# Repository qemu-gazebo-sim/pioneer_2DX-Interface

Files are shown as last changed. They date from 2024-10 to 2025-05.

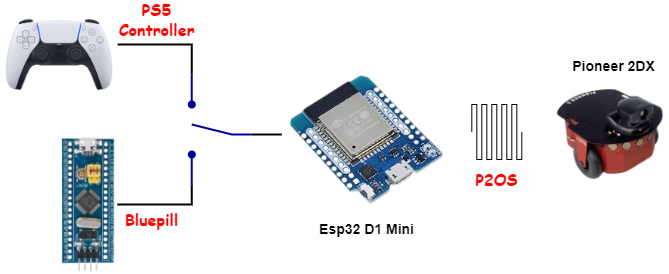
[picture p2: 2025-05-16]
docs/diagramas-test_setup-pioneer_2dx_interface.drawio.png

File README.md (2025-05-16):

<h1 align="center">🤝 Pioneer 2 - Interface | Electronic MVP</h1>
<p align="center"> Electronic Module for the connection between pioneer 2 and Esp32</p>

boards

## 🌎 Real board in the robot

real_robot_with_the_board

## 🧠 Overall board functionality

board_idea

The Pioneer 2DX Interface has the mission to perform the computational logic behind the communication with the Pioneer 2DX and enable for an outside electronic device to send and receive data from the robot. Being more specific for this project, the Pioneer 2DX interface firmware has three main tasks:

- Connect the ESP32 D1 Mini with the bluepill
- Connect the ESP32 D1 Mini with a PS5 controller
- Connect the ESP32 D1 Mini with the pioneer 2DX

The Pioneer 2DX interface allows either a PS5 controller or the Bluepill device to send data to the ESP32, but never simultaneously, as shown in Figure 21. The complete code developed for this interface is available in the GitHub repository of our organization.

The PS5 Controller was added to the project to make it easier to validate the robot’s mechanical and electrical flow without needing to use the autonomous code. This approach allows for identifying issues without suspecting the bluepill code.

algorithm logic

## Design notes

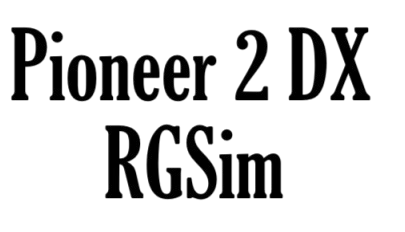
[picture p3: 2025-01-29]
docs/Title.png

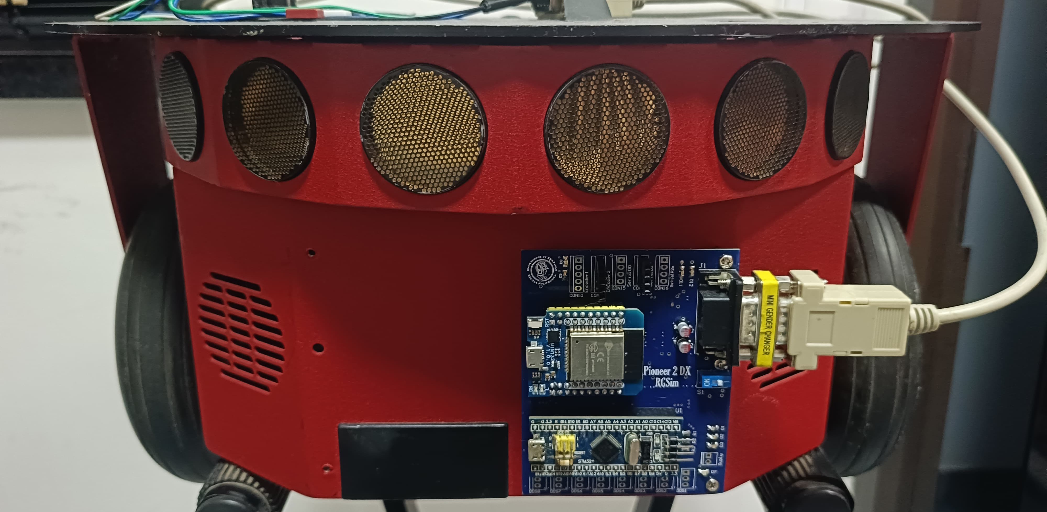
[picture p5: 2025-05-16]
docs/real_robot.jpeg

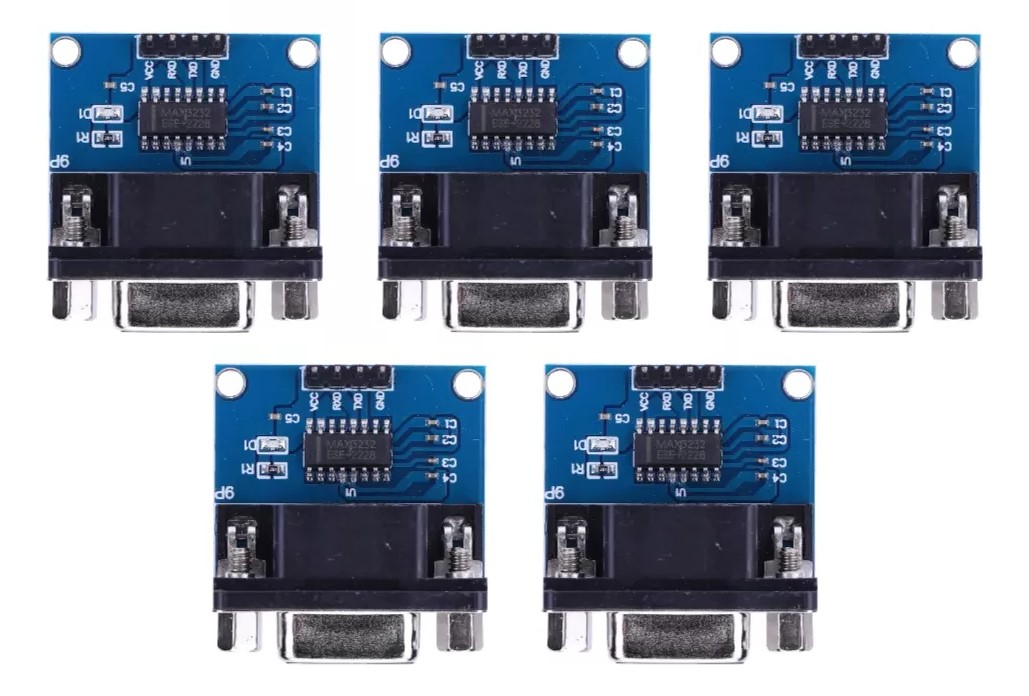
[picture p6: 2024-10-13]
docs/D_NQ_NP_2X_858012-MLB78559910960_082024-F.jpg

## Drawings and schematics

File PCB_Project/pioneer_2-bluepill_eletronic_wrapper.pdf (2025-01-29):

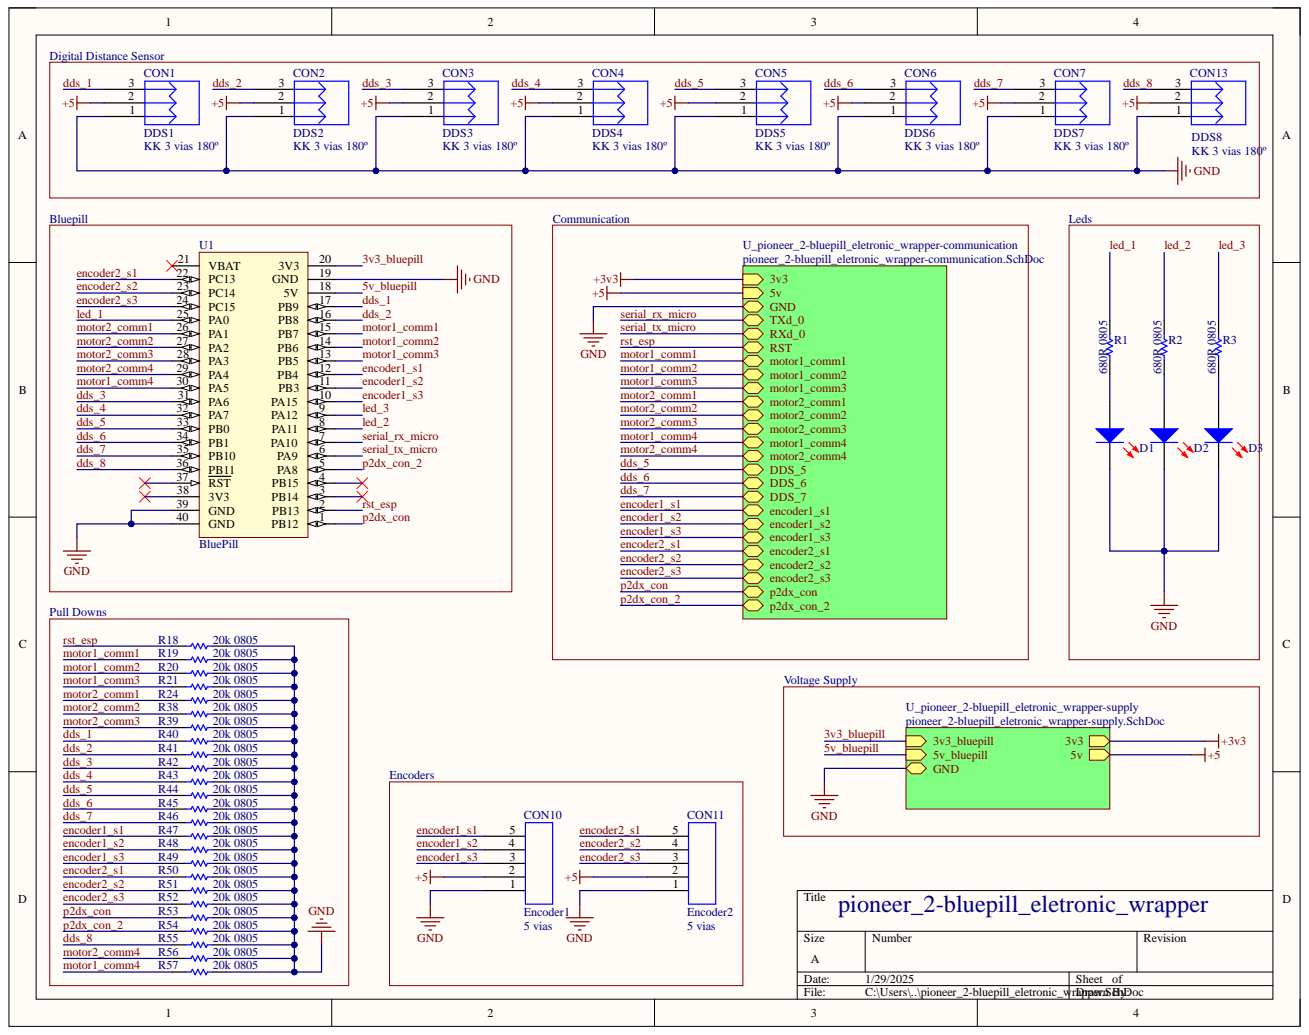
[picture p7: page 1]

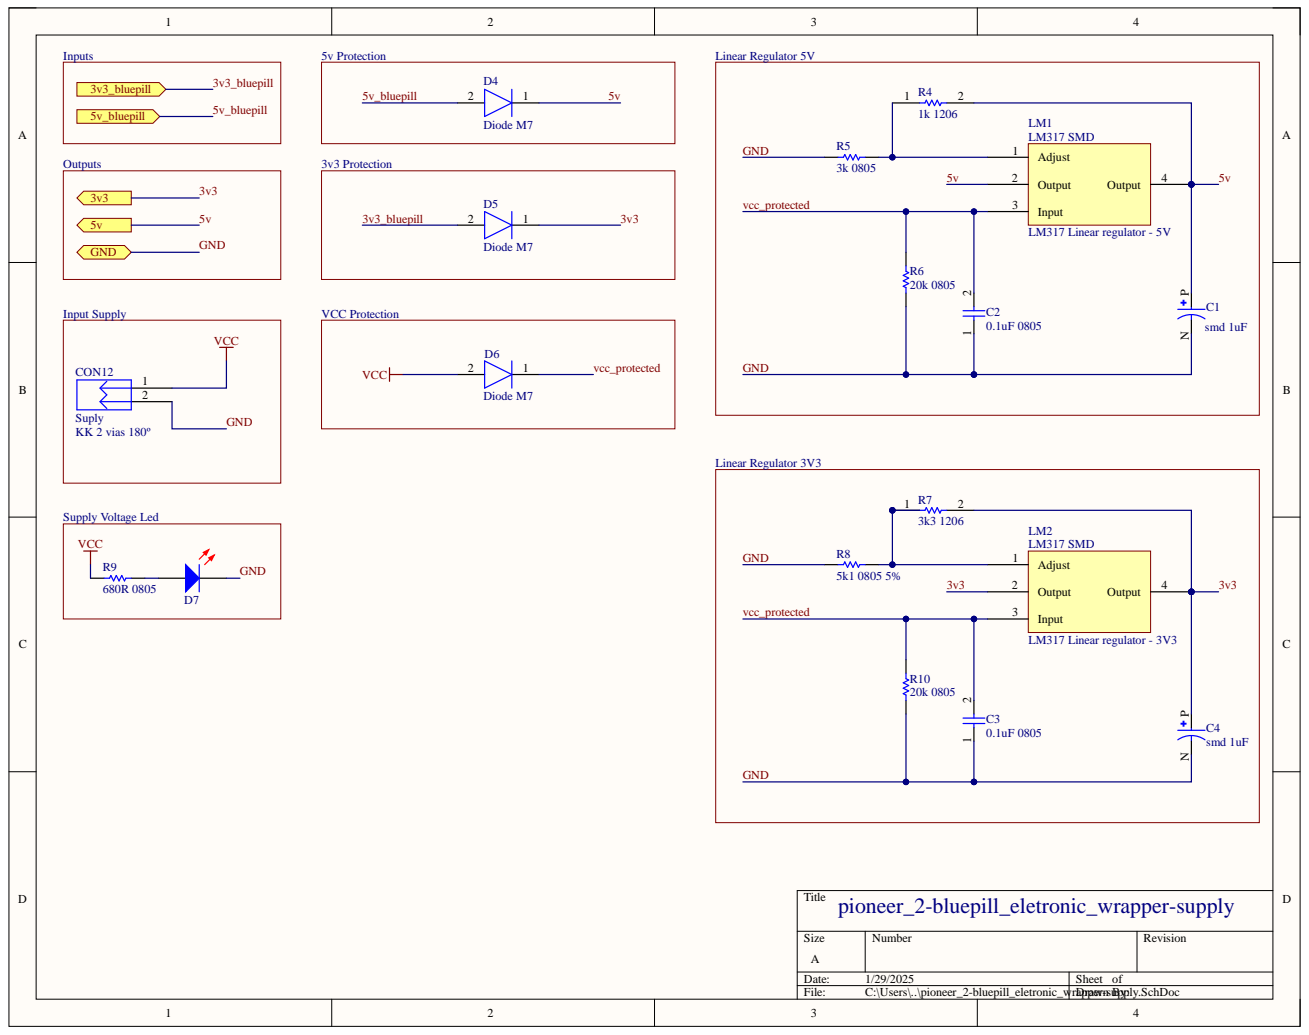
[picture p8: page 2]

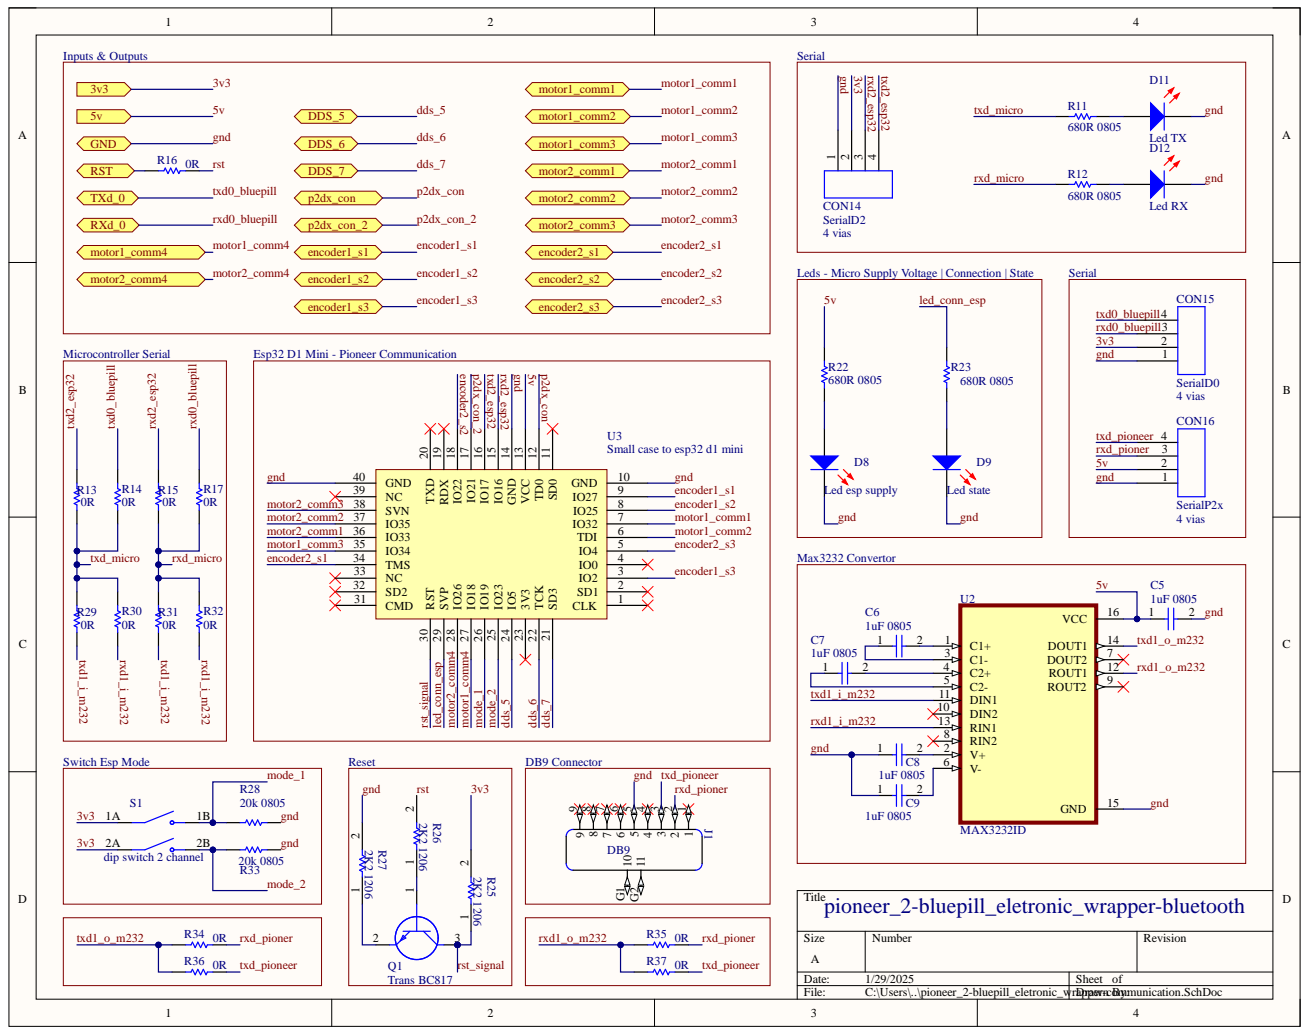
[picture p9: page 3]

Leds - Micro Supply Voltage | Connection | State

Small case to esp32 d1 mini

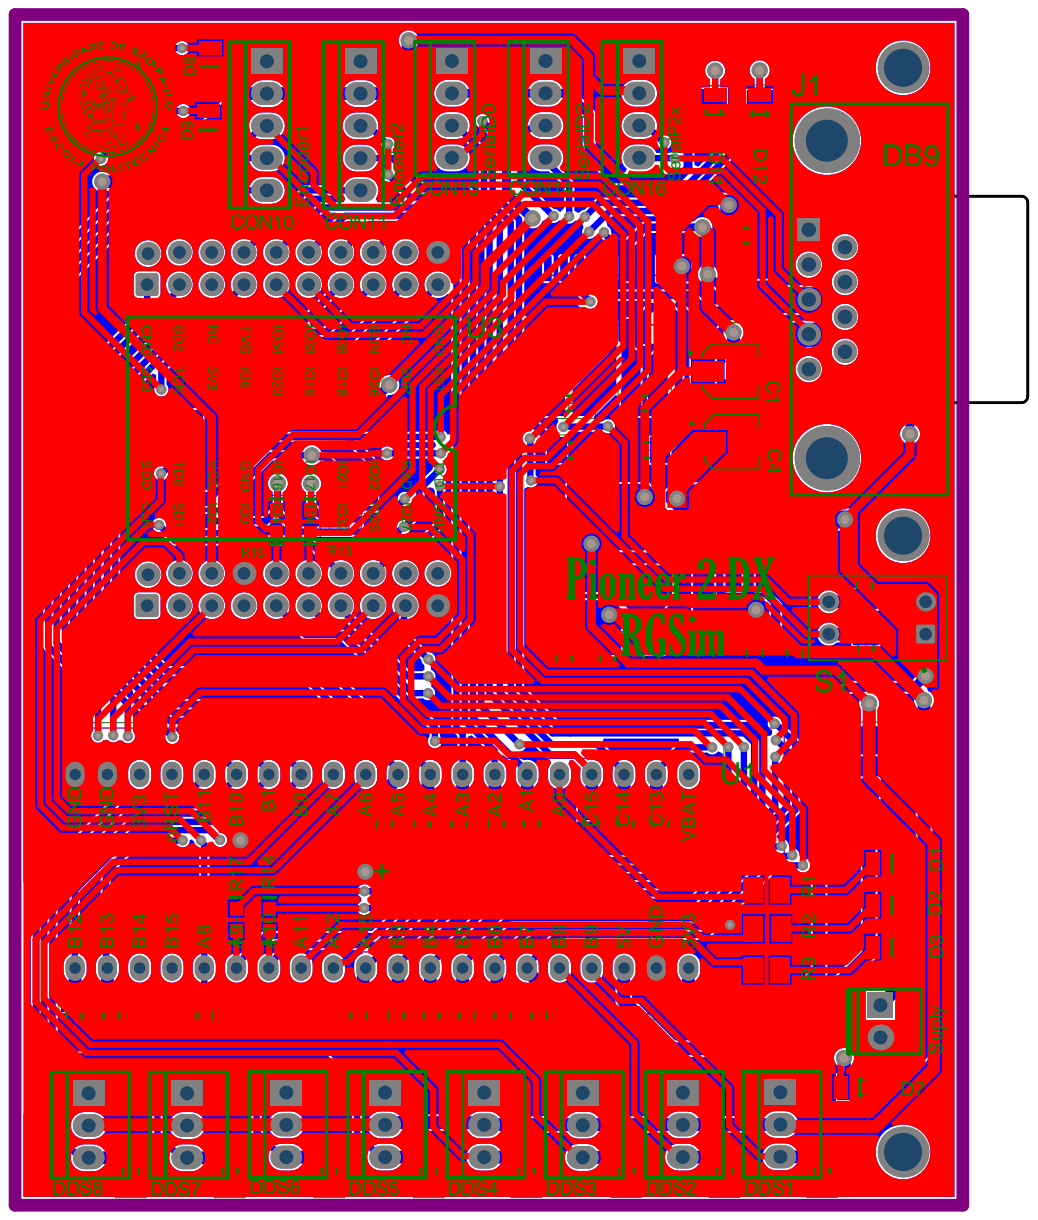
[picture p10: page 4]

Comment | Description | Designator | Footprint | LibRef | Quantity
smd 1uF | Aluminum Organic Polymer Capacitors smd 50volts 1uF | C1, C4 | CAP_EEE1HA2R2SR | Cap. Elet. smd 1uF 50V | 2
0.1uF 0805 | capacitor 0805 | C2, C3 | CAPACITOR 0805 | CAP 0805 | 2
1uF 0805 | capacitor 0805 | C5, C6, C7, C8, C9 | CAPACITOR 0805 | CAP 0805 | 5
DDS1 | Conector KK 2.54mm 3 vias | CON1 | KK_3vias_180º | KK_2.54_3vias | 1
DDS2 | Conector KK 2.54mm 3 vias | CON2 | KK_3vias_180º | KK_2.54_3vias | 1
DDS3 | Conector KK 2.54mm 3 vias | CON3 | KK_3vias_180º | KK_2.54_3vias | 1
DDS4 | Conector KK 2.54mm 3 vias | CON4 | KK_3vias_180º | KK_2.54_3vias | 1
DDS5 | Conector KK 2.54mm 3 vias | CON5 | KK_3vias_180º | KK_2.54_3vias | 1
DDS6 | Conector KK 2.54mm 3 vias | CON6 | KK_3vias_180º | KK_2.54_3vias | 1
DDS7 | Conector KK 2.54mm 3 vias | CON7 | KK_3vias_180º | KK_2.54_3vias | 1
Encoder1 | holes 2.54mm 5 vias | CON10 | 5vias | 2.54_5vias | 1
Encoder2 | holes 2.54mm 5 vias | CON11 | 5vias | 2.54_5vias | 1
Suply | Conector KK 2.54mm 2 vias | CON12 | KK_2VIAS_180º | KK_2.54_2vias | 1
DDS8 | Conector KK 2.54mm 3 vias | CON13 | KK_3vias_180º | KK_2.54_3vias | 1
SerialD2 | holes 2.54mm 4 vias | CON14 | 4vias | 2.54_4vias | 1
SerialD0 | holes 2.54mm 4 vias | CON15 | 4vias | 2.54_4vias | 1
SerialP2x | holes 2.54mm 4 vias | CON16 | 4vias | 2.54_4vias | 1
LED 3MM RED | LED 3MM RED | D1, D2, D3, D7 | LED RED | LED 3MM RED | 4
Diode M7 | Diode, SMA, 1000V, 1A, 150°C | D4, D5, D6 | DIOM505270X240 | Diode M7 | 3
Led esp supply | LED 3MM RED | D8 | LED RED | LED 3MM RED | 1
Led state | LED 3MM RED | D9 | LED RED | LED 3MM RED | 1
Led TX | LED 3MM RED | D11 | LED RED | LED 3MM RED | 1
Led RX | LED 3MM RED | D12 | LED RED | LED 3MM RED | 1
DB9 | Cable Grip 0.38 ~ 0.50 (9.5mm ~ 12.7mm) Aluminum - Silver | J1 | *DB9_DB9(Primary) | DB9 | 1
LM317 Linear regulator - 5V | SOT223 | LM1 | SOT-223-2 | lm317 smd | 1
LM317 Linear regulator - 3V3 | SOT223 | LM2 | SOT-223-2 | lm317 smd | 1
Trans BC817 | Transistor BJT NPN BC817-25-7-F | Q1 | SOT96P240X110-3N | Trans BC817 | 1
680R 0805 | 0805 | R1, R2, R3, R9, R11, R12, R22, R23 | RESISTOR 0805 | RES 0805 5% | 8
1k 1206 | RES 1206 5% | R4 | RESC3216X60N | RES 1206 | 1
3k 0805 | 0805 | R5 | RESISTOR 0805 | RES 0805 5% | 1
20k 0805 | 0805 | R6, R10, R18, R19, R20, R21, R24, R28, R33, R38, R39, R40, R41, R42, R43, R44, R45, R46, R47, R48, R49, R50, R51, R52, R53, R54, R55, R56, R57 | RESISTOR 0805 | RES 0805 5% | 29
3k3 1206 | RES 1206 5% | R7 | RESC3216X60N | RES 1206 | 1
5k1 0805 5% | 0805 | R8 | RESISTOR 0805 | RES 0805 5% | 1
0R | 0603 | R13, R14, R15, R16, R17, R29, R30, R31, R32, R34, R35, R36, R37 | RESISTOR 0603 | RES 0603 5% | 13
2K2 1206 | RES 1206 5% | R25, R26, R27 | RESC3216X60N | RES 1206 | 3
dip switch 2 channel | DS02-254-2L-02BE | S1 | SW_DS02-254-2L-02BE | dip switch 2 channel | 1
BluePill | BluePill - STMDuino (STM32F103) | U1 | BluePill | CMP-010-000000-1 | 1
MAX3232ID | 3-V to 5.5-V multichannel RS-232 line driver & receiver 16-SOIC -40 to 85 | U2 | SOIC127P600X175-16N | MAX3232ID | 1
Small case to esp32 d1 mini | ESP32 D1 Mini | U3 | ESP32 D1 MINI | ESP32 D1 Mini | 1

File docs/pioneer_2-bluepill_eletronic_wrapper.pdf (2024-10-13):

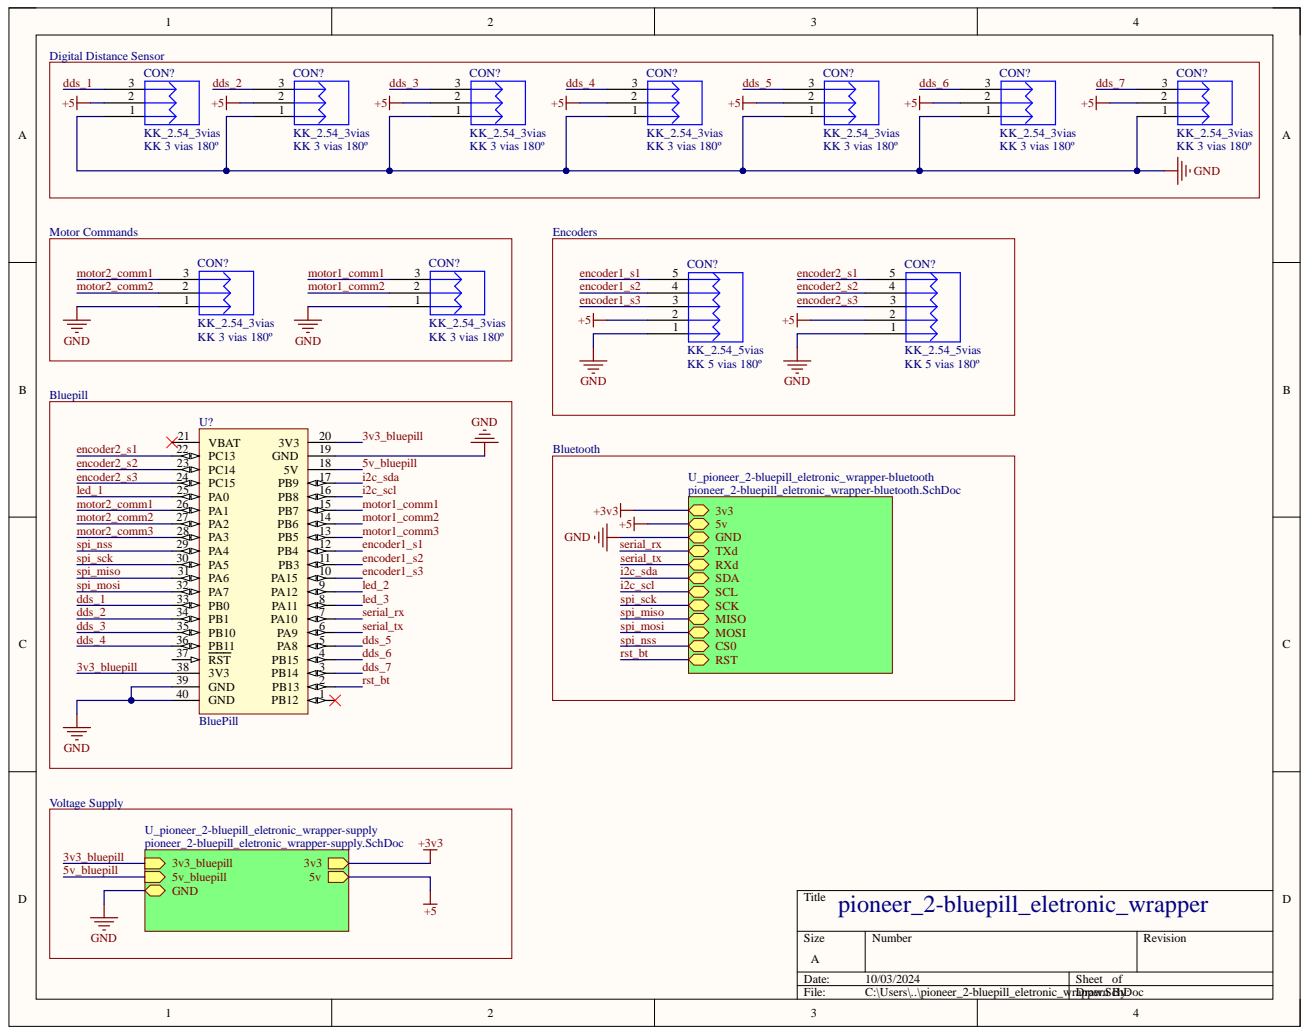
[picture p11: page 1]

GND 39
GND 40

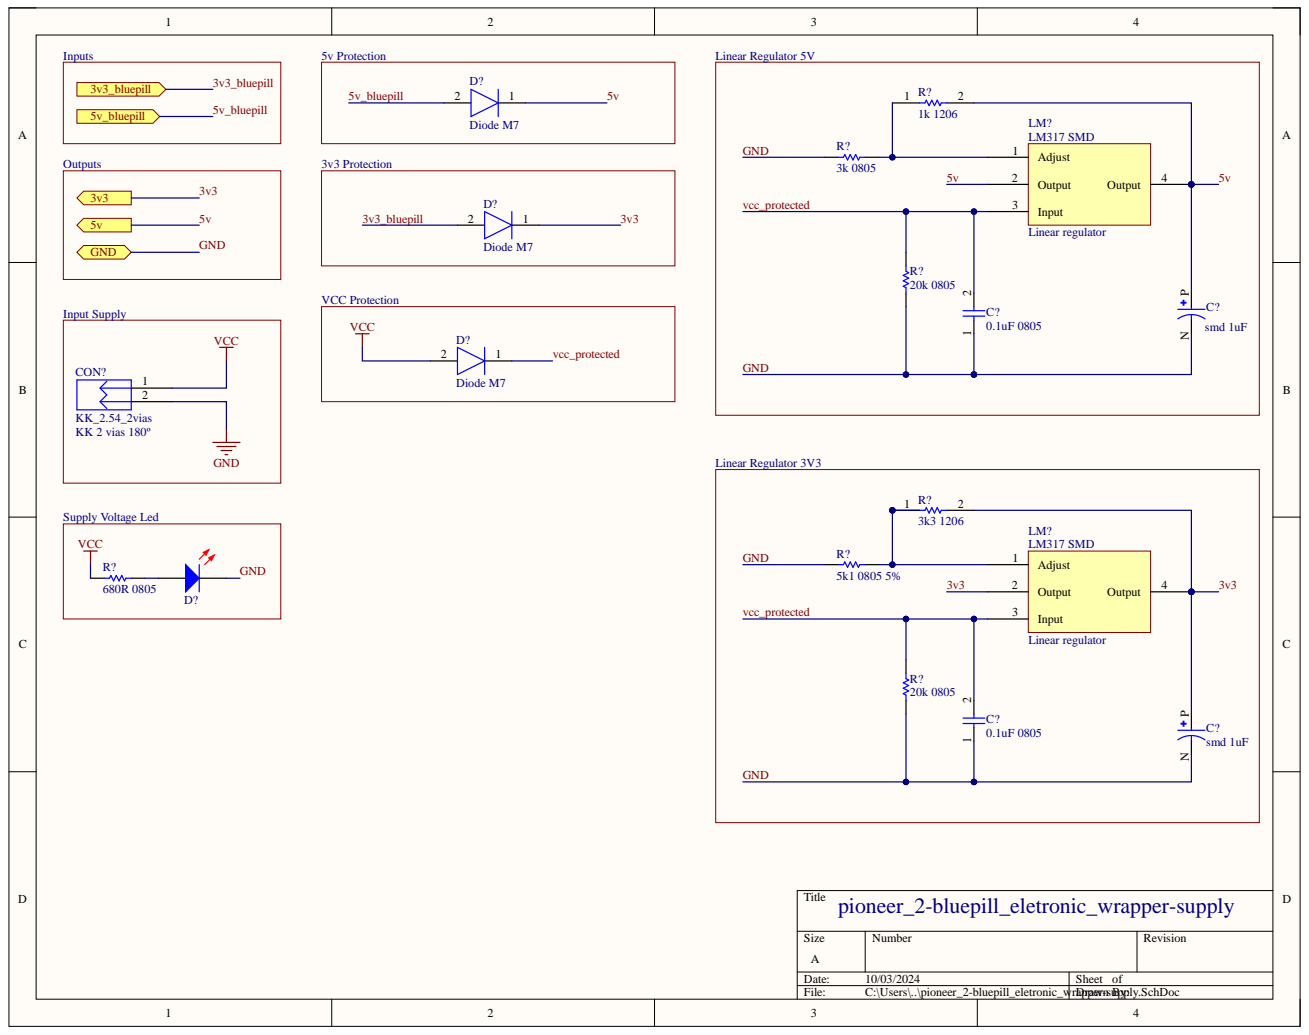
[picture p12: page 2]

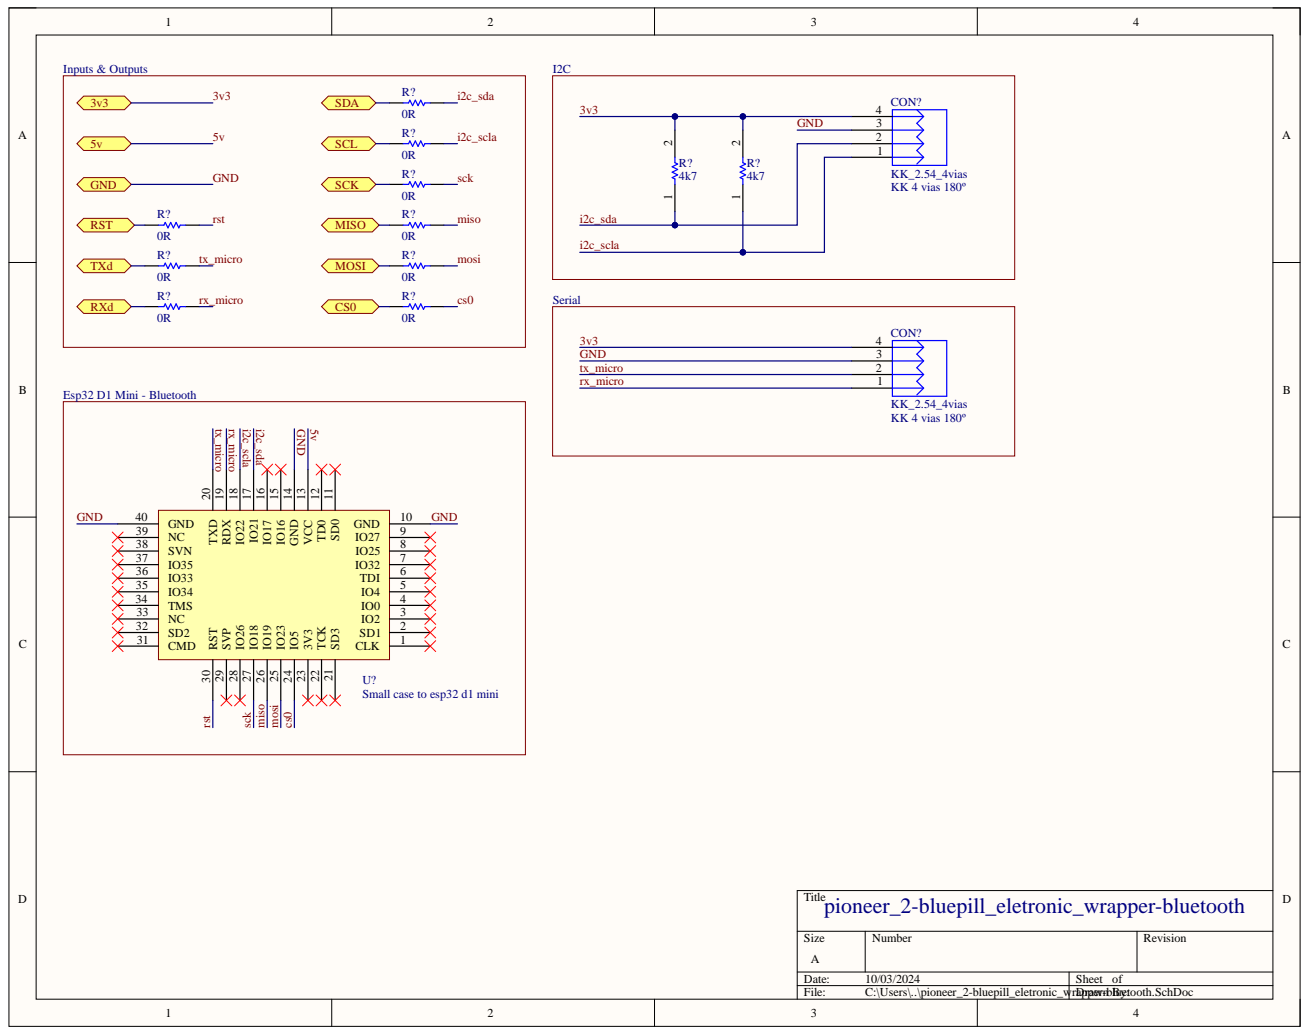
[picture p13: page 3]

Small case to esp32 d1 mini

Comment | Description | Designator | Footprint | LibRef | Quantity
0.1uF 0805 | capacitor 0805 | C? | CAPACITOR 0805 | CAP 0805 | 2
smd 1uF | Aluminum Organic Polymer Capacitors smd 50volts 1uF | C? | CAP_EEE1HA2R2SR | Cap. Elet. smd 1uF 50V | 2
KK_2.54_2vias | Conector KK 2.54mm 2 vias | CON? | KK_2VIAS_180º | KK_2.54_2vias | 1
KK_2.54_3vias | Conector KK 2.54mm 3 vias | CON? | KK_3vias_180º | KK_2.54_3vias | 9
KK_2.54_4vias | Conector KK 2.54mm 4 vias | CON? | KK_4vias_180° | KK_2.54_4vias | 2
KK_2.54_5vias | Conector KK 2.54mm 5 vias | CON? | KK_5vias_180° | KK_2.54_5vias | 2
Diode M7 | Diode, SMA, 1000V, 1A, 150°C | D? | DIOM505270X240 | Diode M7 | 3
LED 3MM RED | LED 3MM RED | D? | LED RED | LED 3MM RED | 1
Linear regulator | | LM? | SOT-223-2 | lm317 smd | 2
0R | 0603 | R? | RESISTOR 0603 | RES 0603 5% | 9
1k 1206 | RES 1206 5% | R? | RESC3216X60N | RES 1206 | 1
3k3 1206 | RES 1206 5% | R? | RESC3216X60N | RES 1206 | 1
3k 0805 | 0805 | R? | RESISTOR 0805 | RES 0805 5% | 1
4k7 | RES 1206 5%, RES 1206 5% SMD | R? | RESC3216X60N | RES 1206 | 2
5k1 0805 5% | 0805 | R? | RESISTOR 0805 | RES 0805 5% | 1
20k 0805 | 0805 | R? | RESISTOR 0805 | RES 0805 5% | 2
680R 0805 | 0805 | R? | RESISTOR 0805 | RES 0805 5% | 1
BluePill | BluePill - STMDuino (STM32F103) | U? | BluePill | CMP-010-000000-1 | 1
Small case to esp32 d1 mini | ESP32 D1 Mini | U? | ESP32 D1 MINI | ESP32 D1 Mini | 1

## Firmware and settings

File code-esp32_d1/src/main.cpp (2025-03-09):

#include "task_controller.hpp"
#include <ArduinoLog.h>

HardwareSerial debug_serial(0);  // define a Serial for UART0

void setup() {
    debug_serial.begin(9600);
    debug_serial.flush();

    Log.begin(LOG_LEVEL_TRACE, &debug_serial);

    TaskController* task_controller = new TaskController();

    task_controller->tasks_init();

    Log.infoln("Ready!");
}

void loop() { }

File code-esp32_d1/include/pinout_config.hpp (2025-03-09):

#ifndef _PINOUT_CONFIG_HPP_
#define _PINOUT_CONFIG_HPP_

/* PS5 Controller mac address */
#define PS5_CONTROLLER_MAC_ADDRESS "10:18:49:7D:EC:F1"

/* P2OS Serial */
#define P2OS_BAUDRATE 9600
#define PIONEER_SERIAL_RX 16
#define PIONEER_SERIAL_TX 17

/* DDS Config */
#define DDS_THRESHOLD 4

#define NUM_DDS 6
#define DDS_1 10
#define DDS_2 13
#define DDS_3 5
#define DDS_4 23
#define DDS_5 19
#define DDS_6 18
#define DDS_7 26
// #define DDS_8

/* Velocity Config */
#define VELOCITY_SAMPLE_INTERVAL 20
// #define VELOCITY_MIN_SAMPLE_NUMBER 5
// #define MOTOR_SAMPLE_INTERVAL 20

#define NUM_MOTOR_COMMS 6
#define MOTOR1_COMM1 32
#define MOTOR1_COMM2 12
#define MOTOR1_COMM3 34
// #define MOTOR1_COMM4 DDS_1 /** The same pins as DDS_1 */

#define MOTOR2_COMM1 33  // 39
#define MOTOR2_COMM2 35  // 35
#define MOTOR2_COMM3 39  // 33
// #define MOTOR2_COMM4 DDS_1 /** The same pins as DDS_2 */

/* Encoder Config */
#define NUM_ENCODERS_PIN 6
#define ENCODER1_S1 27
#define ENCODER1_S2 25
#define ENCODER1_S3 2
#define ENCODER2_S1 14
#define ENCODER2_S2 22
#define ENCODER2_S3 4

/* Connection pin Config */
#define CONNECTION_SAMPLE_INTERVAL 10
#define P2DX_CON 15
#define P2DX_CON_2 21

/* Connection pin Config */
// #define LED_CONN 36

/* Switch */
#define MODE_1_PIN 19
#define MODE_2_PIN 23

#endif  // _PINOUT_CONFIG_HPP_

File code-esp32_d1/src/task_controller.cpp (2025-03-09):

#include <Arduino.h>
#include <ArduinoLog.h>

#include <ps5Controller.h>
#include "task_controller.hpp"

#include "pinout_config.hpp"
#include <p2os.hpp>
#include "bluepill_comm.hpp"
#include "utils.hpp"

static const QueueHandle_t msg_queue_vel = xQueueCreate(1, sizeof(geometry_msgs::Twist));
static const QueueHandle_t msg_queue_conn_command = xQueueCreate(1, sizeof(ConnectionStates));
static const QueueHandle_t msg_queue_sensors = xQueueCreate(1, sizeof(nav_msgs::ros_p2os_data_t));

/* Private functions */
OperationalModes TaskController::set_current_operational_mode() {
    switch (digitalRead(MODE_1_PIN)) {
        case 0:
            this->current_operational_mode = BLUETOOTH_MODE;
            break;

        case 1:
            this->current_operational_mode = BLUEPILL_MODE;
            break;

        default:
            Log.errorln("TaskController::get_current_operational_mode() not valid mode");
            this->current_operational_mode = BLUETOOTH_MODE;
            break;
    }

    return this->current_operational_mode;
}

/* Public functions */
TaskController::TaskController() {
    pinMode(MODE_1_PIN, INPUT);
    // pinMode(MODE_2_PIN, INPUT);
    // pinMode(LED_CONN, OUTPUT);

    this->set_current_operational_mode();
    this->size_base = 1024;
}

TaskController::~TaskController() { }

void TaskController::tasks_init() {
    Log.traceln("TaskController::tasks_init()");
    switch (this->get_current_operational_mode()) {
        case BLUEPILL_MODE:
            Log.infoln("Starting on Bluepill mode");
            xTaskCreatePinnedToCore(
                this->bluepill_task, "TaskBluepill", this->size_base * 10, NULL, 1, &(this->TaskBluepill), 0
            );
            // digitalWrite(LED_CONN, LOW);
            break;

        case BLUETOOTH_MODE:
            Log.traceln("Starting on BT mode");
            xTaskCreatePinnedToCore(
                this->bluetooth_task, "TaskBluetooth", this->size_base * 4, NULL, 1, &(this->TaskBluetooth), 0
            );
            // digitalWrite(LED_CONN, HIGH);
            break;

        default:
            Log.errorln("TaskController::TaskController() init error");
            return;
    }

    xTaskCreatePinnedToCore(this->p2os_task, "TaskP2OS", this->size_base * 4, NULL, 1, &(this->TaskP2OS), 1);
}

OperationalModes TaskController::get_current_operational_mode() {
    return this->current_operational_mode;
}

/* Protected functions */
void TaskController::bluetooth_task(void* pvParameters) {
    Log.traceln("Starting on BT task");

    ps5.begin(PS5_CONTROLLER_MAC_ADDRESS);  // replace with MAC address of your controller
    uint32_t             current_loop_time_bt;
    geometry_msgs::Twist msg_vel;

    while (true) {
        ConnectionStates is_connected_bt = NOT_CONNECTED;
        uint16_t         current_r2_val = 0;
        uint16_t         current_l2_val = 0;
        int16_t          current_rs_x_val = 0;

        ConnectionStates connection_command;
        bool             need_send_connect_msg = false;

        while (ps5.isConnected() == true) {
            current_loop_time_bt = millis();

            if (ps5.Up()) {
                connection_command = CONNECTED;
                need_send_connect_msg = true;
            }

            if (ps5.Down()) {
                connection_command = NOT_CONNECTED;
                need_send_connect_msg = true;
            }

            if (need_send_connect_msg && msg_queue_conn_command != 0) {
                if (xQueueSend(msg_queue_conn_command, &connection_command, portMAX_DELAY) == pdTRUE) {
                    need_send_connect_msg = false;
                    is_connected_bt = connection_command;
                }
            }

            if (is_connected_bt == CONNECTED) {
                current_r2_val = scale(ps5.R2Value(), 0, 255, 0, 500);
                current_l2_val = scale(ps5.L2Value(), 0, 255, 0, 500);
                current_rs_x_val = (-1) * scale(ps5.RStickX(), -128, 128, -170, 170);

                msg_vel.linear.x = double(double(current_r2_val - current_l2_val) / 1000);
                msg_vel.angular.z = double(current_rs_x_val) / 100;

                if (xQueueOverwrite(msg_queue_vel, &msg_vel) == pdFALSE) {
                    Log.infoln("Failed to send the data");
                }
            }

            Log.verboseln("BT: current_loop_time: %l", (millis() - current_loop_time_bt));
            vTaskDelay(1 / portTICK_PERIOD_MS);
        }

        vTaskDelay(1000 / portTICK_PERIOD_MS);
    }
}

void TaskController::bluepill_task(void* pvParameters) {
    ConnectionStates          current_connected_state = NOT_CONNECTED;
    bool                      need_send_connect_msg = false;
    geometry_msgs::Twist      current_vel;
    nav_msgs::ros_p2os_data_t data_from_p2os;

    BluepillCommunication* bluepill_comm = new BluepillCommunication();

    uint32_t connection_time = millis();
    uint32_t current_loop_time_bluepill;

    while (true) {
        current_loop_time_bluepill = millis();
        bluepill_comm->loop();

        if (current_connected_state != bluepill_comm->is_bluepill_connected() &&
            ((millis() - connection_time) > 1000)) {
            switch (bluepill_comm->is_bluepill_connected()) {
                case CONNECTED:
                    current_connected_state = CONNECTED;
                    need_send_connect_msg = true;
                    break;
                case NOT_CONNECTED:
                    current_connected_state = NOT_CONNECTED;
                    need_send_connect_msg = true;
                    break;
                default:
                    current_connected_state = CONNECTED;
                    // Log.infoln("Error: Cry! - switch (bluepill_comm->is_bluepill_connected())");
                    break;
            }

            if (need_send_connect_msg && msg_queue_conn_command != 0) {
                if (xQueueSend(msg_queue_conn_command, &current_connected_state, portMAX_DELAY) == pdTRUE) {
                    need_send_connect_msg = false;
                }
            }

            bluepill_comm->send_bluepill_connection(current_connected_state);
        }

        current_vel = bluepill_comm->get_velocity();

        if (xQueueOverwrite(msg_queue_vel, &current_vel) == pdFALSE) {
            Log.infoln("BP: Failed to send the data");
        }

        if (msg_queue_sensors != 0) {
            if (xQueueReceive(msg_queue_sensors, &data_from_p2os, (1 / portTICK_PERIOD_MS)) == pdTRUE) {
                bluepill_comm->update_p2dx_data(data_from_p2os);
            }
        }

        // vTaskDelay(10 / portTICK_PERIOD_MS);
        Log.verboseln("BP: current_loop_time: %ld", (millis() - current_loop_time_bluepill));
    }
}
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

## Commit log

2024-09-26 🎉 initial commit
2024-09-26 🏗️ add initial architecture
    [pioneer_2-bluepill_eletronic_wrapper.PcbDoc, pioneer_2-bluepill_eletronic_wrapper.PrjPcb, pioneer_2-bluepill_eletronic_wrapper.SchDoc]
2024-09-29 add project rules and pcb
    [pioneer_2-bluepill_eletronic_wrapper.PcbDoc, pioneer_2-bluepill_eletronic_wrapper.SchDoc]
2024-09-29 update main pcb
    [pioneer_2-bluepill_eletronic_wrapper-supply.SchDoc, pioneer_2-bluepill_eletronic_wrapper.PrjPcb, pioneer_2-bluepill_eletronic_wrapper.SchDoc]
2024-10-03 update pcb schematic
    [pioneer_2-bluepill_eletronic_wrapper-bluetooth.SchDoc, pioneer_2-bluepill_eletronic_wrapper-supply.SchDoc, pioneer_2-bluepill_eletronic_wrapper.PcbDoc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]
2024-10-03 add linear regulator simulation
    [pioneer_2-bluepill_eletronic_wrapper-supply.SchDoc, pioneer_2-bluepill_eletronic_wrapper.SchDoc]
2024-10-13 add max3232 to schematic
    [pioneer_2-bluepill_eletronic_wrapper-bluetooth.SchDoc, pioneer_2-bluepill_eletronic_wrapper-communication.SchDoc]
2024-10-17 add platformio prototype code
2024-10-20 update esp32 code
2024-10-22 update esp32 d1 code
2024-11-03 update esp32 p2os code
2024-11-07 update wrapper - 1 funcional version
    [pioneer_2-bluepill_eletronic_wrapper-communication.SchDoc, pioneer_2-bluepill_eletronic_wrapper-supply.SchDoc, pioneer_2-bluepill_eletronic_wrapper.PrjPcb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]
2024-11-09 update pcb project
    [pioneer_2-bluepill_eletronic_wrapper-communication.SchDoc, pioneer_2-bluepill_eletronic_wrapper.PrjPcb, pioneer_2-bluepill_eletronic_wrapper.SchDoc]
2024-11-23 add main code prototype
2024-12-09 update esp32 config pins
2024-12-11 format esp32 code
2025-01-29 update pcb pdf file
    [pioneer_2-bluepill_eletronic_wrapper.SchDoc]
2025-01-29 update pcbway zip file
2025-03-02 update esp32 d1 tests
2025-03-09 add arduino log and add task controller
2025-03-09 update p2os arduino library
2025-05-16 update project PCB
    [pioneer_2-bluepill_eletronic_wrapper-communication.SchDoc]
